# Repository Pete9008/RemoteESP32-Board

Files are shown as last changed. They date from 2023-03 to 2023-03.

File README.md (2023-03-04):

# RemoteESP32-Board
Stand alone 12V ESP32 module with SD card and RS485 and CAN bus interfaces

# Usage
This board is intended to be used with this firmware: https://github.com/Pete9008/esp32-web-interface/tree/Remote485 which currently supports use of the RS485 interface in either half or full duplex mode.

The BOM reflects the build for full duplex (4-wire RS485).  To use this the following line in the firmware needs to be commented out:
line88 - //#define RS485_HALF_DUPLEX 1

To use in half duplex mode (2-wire RS485) resistors R23 and R24 must have zero ohm links fitted (Note - This mode is not compatible with the standard OpenInverter firmware.

The firmware does not currently support CAN bus operation.  The CAN interface is currently untested.

# Powering
The board needs a 12V power supply connected on header J4.

0V connects to Pin-2
12V connects to Pin-1 (WiFi only mode)
12V connects to Pin-3 (SD card logging mode)

If power is supplied on Pin-1 then SD card logging is disabled (SD card files can still be read over the web interface though).

If power is supplied on Pin-3 then SD card logging will start (but only while there is no connection on the WiFi).

Note - Not all OpenInverter firmware versions support logging.

# SD Card Interface
The SD card uses the SDIO interface to allow high speed logging.  This requires a pull up on the D2 line (GPIO12) which prevents ESP32-WROOM-32E modules from booting from internal flash.

If the SD card is not used do not populate R9 (D2 pullup).

If the SD card is required then the module must have the flash voltage selection eFuses burned BEFORE resistor R9 is fitted.  See https://docs.espressif.com/projects/esp-idf/en/latest/esp32/api-reference/peripherals/sd_pullup_requirements.html for details of the fuse burning process.

# Programming Interface
Header J3 provides a programming interface for the board.  An external USB to 3V3 TTL 232 converter dongle is required to connect to this header.  To place the ESP32 into programming mode pins 1 and 2 of the header must be linked.  Pin-6 on the header can then either be grounded manually to reset the ESP32 and enter programming mode or can connected to RTS on the dongle (a reset will then be generated automatically by the esptool programming software).  The Tx line on the dongle connects to header Pin-4 and the Rx line to header Pin-5.  Header Pin-1 should connect to dongle 0V/GND.

Power during programming must be supplied by connecting 12V on the power header J4.

# Enclosure
Two versions of a 3D printable enclosure are included:
RemoteESP32_Enclosure_NoBat.FCStd - Slim enclosure but without enough space for the RTC backup battery.
RemoteESP32_Enclosure_Bat.FCStd - Larger enclosure with space for the RTC battery.

Both are in FreeCAD format.  .stl files for the enclosure base and lid are also included.

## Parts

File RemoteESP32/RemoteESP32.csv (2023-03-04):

Source: | /home/pete/Kicad/RemoteESP32/RemoteESP32/RemoteESP32.kicad_sch
Date: | Sat 04 Mar 2023 18:39:13 GMT
Tool: | Eeschema 6.0.0-d3dd2cf0fa~116~ubuntu18.04.1
Generator: | /usr/share/kicad/plugins/bom_csv_grouped_by_value.py
Component Count: | 58
Individual Components:
Item | Qty | Reference(s) | Value | LibPart | Footprint | Datasheet | Part | Voltage
 |  | BT1 | BR1225 | Device:Battery_Cell | Battery:Battery_Panasonic_CR1220-VCN_Vertical_CircularHoles | ~
 |  | C1 | 10u | Device:C | Capacitor_SMD:C_1206_3216Metric | ~ | CL31A106MBHNNNE | 50V
 |  | C2 | 100n | Device:C | Capacitor_SMD:C_0603_1608Metric | ~
 |  | C3 | 100n | Device:C | Capacitor_SMD:C_0603_1608Metric | ~
 |  | C4 | 100n | Device:C | Capacitor_SMD:C_0603_1608Metric | ~
 |  | C5 | 100n | Device:C | Capacitor_SMD:C_0603_1608Metric | ~
 |  | C6 | 100n | Device:C | Capacitor_SMD:C_0603_1608Metric | ~
 |  | C7 | 10u 50V | Device:C | Capacitor_SMD:C_1206_3216Metric | ~ | CL31A106MBHNNNE
 |  | C8 | 220p | Device:C | Capacitor_SMD:C_0603_1608Metric | ~
 |  | C9 | 100u | Device:C_Polarized | Capacitor_Tantalum_SMD:CP_EIA-7343-31_Kemet-D | ~ |  | 10V
 |  | C10 | 100n | Device:C | Capacitor_SMD:C_0603_1608Metric | ~
 |  | C11 | 10u | Device:C | Capacitor_SMD:C_1206_3216Metric | ~ | CL31A106MBHNNNE | 50V
 |  | C12 | 100n | Device:C | Capacitor_SMD:C_0603_1608Metric | ~
 |  | C13 | 100n | Device:C | Capacitor_SMD:C_0603_1608Metric | ~
 |  | D1 | MRA4003T3G | Diode:MRA4003T3G | Diode_SMD:D_SMA | http://www.onsemi.com/pub_link/Collateral/MRA4003T3-D.PDF
 |  | D2 | BAS40-04 | Diode:BAS40-04 | Package_TO_SOT_SMD:SOT-23 | http://www.vishay.com/docs/85701/bas40v.pdf | BAS40-04
 |  | D3 | BAS40-04 | Diode:BAS40-04 | Package_TO_SOT_SMD:SOT-23 | http://www.vishay.com/docs/85701/bas40v.pdf | BAS40-04
 |  | D4 | MRA4003T3G | Diode:MRA4003T3G | Diode_SMD:D_SMA | http://www.onsemi.com/pub_link/Collateral/MRA4003T3-D.PDF
 |  | D5 | PMEG60T30ELP | Diode:PMEG60T30ELR | Diode_SMD:D_SOD-128 | https://assets.nexperia.com/documents/data-sheet/PMEG60T30ELR.pdf | PMEG60T30ELP
 |  | H1 | MountingHole | Mechanical:MountingHole | MountingHole:MountingHole_2.2mm_M2_DIN965 | ~
 |  | H2 | MountingHole | Mechanical:MountingHole | MountingHole:MountingHole_2.2mm_M2_DIN965 | ~
 |  | H3 | MountingHole | Mechanical:MountingHole | MountingHole:MountingHole_2.2mm_M2_DIN965 | ~
 |  | H4 | MountingHole | Mechanical:MountingHole | MountingHole:MountingHole_2.2mm_M2_DIN965 | ~
 |  | J1 | Conn_01x07 | Connector_Generic:Conn_01x07 | Connector_Molex:Molex_KK-254_AE-6410-07A_1x07_P2.54mm_Vertical | ~
 |  | J2 | Molex_104031-0811 | Connector:Micro_SD_Card_Det_Hirose_DM3AT | Connector_Card:microSD_HC_Molex_104031-0811 | https://www.hirose.com/product/en/download_file/key_name/DM3/category/Catalog/doc_file_id/49662/?item_id=195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 | 104031-0811
 |  | J3 | Conn_01x06 | Connector_Generic:Conn_01x06 | Connector_PinHeader_2.54mm:PinHeader_1x06_P2.54mm_Vertical | ~
 |  | J4 | Conn_01x03 | Connector_Generic:Conn_01x03 | Connector_Molex:Molex_KK-254_AE-6410-03A_1x03_P2.54mm_Vertical | ~
 |  | L1 | 100u | Device:L | Inductor_SMD:L_Bourns_SRR1260 | ~ | SRR1260-101M
 |  | R1 | 10k | Device:R | Resistor_SMD:R_0603_1608Metric | ~
 |  | R2 | NF | Device:R | Resistor_SMD:R_0603_1608Metric | ~
 |  | R3 | 51k | Device:R | Resistor_SMD:R_0603_1608Metric | ~
 |  | R4 | 10k | Device:R | Resistor_SMD:R_0603_1608Metric | ~
 |  | R5 | NF | Device:R | Resistor_SMD:R_0603_1608Metric | ~
 |  | R6 | 10k | Device:R | Resistor_SMD:R_0603_1608Metric | ~
 |  | R7 | 10k | Device:R | Resistor_SMD:R_0603_1608Metric | ~
 |  | R8 | 10k | Device:R | Resistor_SMD:R_0603_1608Metric | ~
 |  | R9 | 10k | Device:R | Resistor_SMD:R_0603_1608Metric | ~
 |  | R10 | 10k | Device:R | Resistor_SMD:R_0603_1608Metric | ~
 |  | R11 | NF | Device:R | Resistor_SMD:R_0603_1608Metric | ~
 |  | R12 | 10k | Device:R | Resistor_SMD:R_0603_1608Metric | ~
 |  | R13 | 10k | Device:R | Resistor_SMD:R_0603_1608Metric | ~
 |  | R14 | 10k | Device:R | Resistor_SMD:R_0603_1608Metric | ~
 |  | R15 | 10k | Device:R | Resistor_SMD:R_0603_1608Metric | ~
 |  | R16 | 2k2 | Device:R | Resistor_SMD:R_0603_1608Metric | ~
 |  | R17 | 0R4 | Device:R | Resistor_SMD:R_1206_3216Metric | ~
 |  | R18 | 3k6 | Device:R | Resistor_SMD:R_0603_1608Metric | ~
 |  | R19 | 2k2 | Device:R | Resistor_SMD:R_0603_1608Metric | ~
 |  | R20 | 2k2 | Device:R | Resistor_SMD:R_0603_1608Metric | ~
 |  | R21 | 120R | Device:R | Resistor_SMD:R_0603_1608Metric | ~
 |  | R22 | 120R | Device:R | Resistor_SMD:R_0603_1608Metric | ~
 |  | R23 | NF | Device:R | Resistor_SMD:R_0603_1608Metric | ~
 |  | R24 | NF | Device:R | Resistor_SMD:R_0603_1608Metric | ~
 |  | U1 | SN65HVD230 | Interface_CAN_LIN:SN65HVD230 | Package_SO:SOIC-8_3.9x4.9mm_P1.27mm | http://www.ti.com/lit/ds/symlink/sn65hvd230.pdf
 |  | U2 | PCF8523T | Timer_RTC:PCF8523T | Package_SO:SOIC-8_3.9x4.9mm_P1.27mm | https://www.nxp.com/docs/en/data-sheet/PCF8523.pdf
 |  | U3 | ISL83076E | project:ISL83070 | Package_SO:SO-14_3.9x8.65mm_P1.27mm
 |  | U4 | MC33063AD | Regulator_Switching:MC33063AD | Package_SO:SOIC-8_3.9x4.9mm_P1.27mm | http://www.onsemi.com/pub_link/Collateral/MC34063A-D.PDF | MC33063AD
 |  | U5 | ESP32-WROOM-32E | RF_Module:ESP32-WROOM-32D | RF_Module:ESP32-WROOM-32 | https://www.espressif.com/sites/default/files/documentation/esp32-wroom-32d_esp32-wroom-32u_datasheet_en.pdf
 |  | Y1 | 32.768kHz | Device:Crystal_GND3_Small | Crystal:Crystal_AT310_D3.0mm_L10.0mm_Horizontal_1EP_style2 | ~
Collated Components:
Item | Qty | Reference(s) | Value | LibPart | Footprint | Datasheet | Part | Voltage
1 | 1 | BT1 | BR1225 | Device:Battery_Cell | Battery:Battery_Panasonic_CR1220-VCN_Vertical_CircularHoles | ~
2 | 2 | C1, C11 | 10u | Device:C | Capacitor_SMD:C_1206_3216Metric | ~ | CL31A106MBHNNNE | 50V
3 | 8 | C2, C3, C4, C5, C6, C10, C12, C13 | 100n | Device:C | Capacitor_SMD:C_0603_1608Metric | ~
4 | 1 | C7 | 10u 50V | Device:C | Capacitor_SMD:C_1206_3216Metric | ~ | CL31A106MBHNNNE
5 | 1 | C8 | 220p | Device:C | Capacitor_SMD:C_0603_1608Metric | ~
6 | 1 | C9 | 100u | Device:C_Polarized | Capacitor_Tantalum_SMD:CP_EIA-7343-31_Kemet-D | ~ |  | 10V
7 | 2 | D1, D4 | MRA4003T3G | Diode:MRA4003T3G | Diode_SMD:D_SMA | http://www.onsemi.com/pub_link/Collateral/MRA4003T3-D.PDF
8 | 2 | D2, D3 | BAS40-04 | Diode:BAS40-04 | Package_TO_SOT_SMD:SOT-23 | http://www.vishay.com/docs/85701/bas40v.pdf | BAS40-04
9 | 1 | D5 | PMEG60T30ELP | Diode:PMEG60T30ELR | Diode_SMD:D_SOD-128 | https://assets.nexperia.com/documents/data-sheet/PMEG60T30ELR.pdf | PMEG60T30ELP
10 | 4 | H1, H2, H3, H4 | MountingHole | Mechanical:MountingHole | MountingHole:MountingHole_2.2mm_M2_DIN965 | ~
11 | 1 | J1 | Conn_01x07 | Connector_Generic:Conn_01x07 | Connector_Molex:Molex_KK-254_AE-6410-07A_1x07_P2.54mm_Vertical | ~
12 | 1 | J2 | Molex_104031-0811 | Connector:Micro_SD_Card_Det_Hirose_DM3AT | Connector_Card:microSD_HC_Molex_104031-0811 | https://www.hirose.com/product/en/download_file/key_name/DM3/category/Catalog/doc_file_id/49662/?item_id=195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 | 104031-0811
13 | 1 | J3 | Conn_01x06 | Connector_Generic:Conn_01x06 | Connector_PinHeader_2.54mm:PinHeader_1x06_P2.54mm_Vertical | ~
14 | 1 | J4 | Conn_01x03 | Connector_Generic:Conn_01x03 | Connector_Molex:Molex_KK-254_AE-6410-03A_1x03_P2.54mm_Vertical | ~
15 | 1 | L1 | 100u | Device:L | Inductor_SMD:L_Bourns_SRR1260 | ~ | SRR1260-101M
16 | 11 | R1, R4, R6, R7, R8, R9, R10, R12, R13, R14, R15 | 10k | Device:R | Resistor_SMD:R_0603_1608Metric | ~
17 | 5 | R2, R5, R11, R23, R24 | NF | Device:R | Resistor_SMD:R_0603_1608Metric | ~
18 | 1 | R3 | 51k | Device:R | Resistor_SMD:R_0603_1608Metric | ~
19 | 3 | R16, R19, R20 | 2k2 | Device:R | Resistor_SMD:R_0603_1608Metric | ~
20 | 1 | R17 | 0R4 | Device:R | Resistor_SMD:R_1206_3216Metric | ~
21 | 1 | R18 | 3k6 | Device:R | Resistor_SMD:R_0603_1608Metric | ~
22 | 2 | R21, R22 | 120R | Device:R | Resistor_SMD:R_0603_1608Metric | ~
23 | 1 | U1 | SN65HVD230 | Interface_CAN_LIN:SN65HVD230 | Package_SO:SOIC-8_3.9x4.9mm_P1.27mm | http://www.ti.com/lit/ds/symlink/sn65hvd230.pdf
24 | 1 | U2 | PCF8523T | Timer_RTC:PCF8523T | Package_SO:SOIC-8_3.9x4.9mm_P1.27mm | https://www.nxp.com/docs/en/data-sheet/PCF8523.pdf
25 | 1 | U3 | ISL83076E | project:ISL83070 | Package_SO:SO-14_3.9x8.65mm_P1.27mm
26 | 1 | U4 | MC33063AD | Regulator_Switching:MC33063AD | Package_SO:SOIC-8_3.9x4.9mm_P1.27mm | http://www.onsemi.com/pub_link/Collateral/MC34063A-D.PDF | MC33063AD
27 | 1 | U5 | ESP32-WROOM-32E | RF_Module:ESP32-WROOM-32D | RF_Module:ESP32-WROOM-32 | https://www.espressif.com/sites/default/files/documentation/esp32-wroom-32d_esp32-wroom-32u_datasheet_en.pdf
28 | 1 | Y1 | 32.768kHz | Device:Crystal_GND3_Small | Crystal:Crystal_AT310_D3.0mm_L10.0mm_Horizontal_1EP_style2 | ~

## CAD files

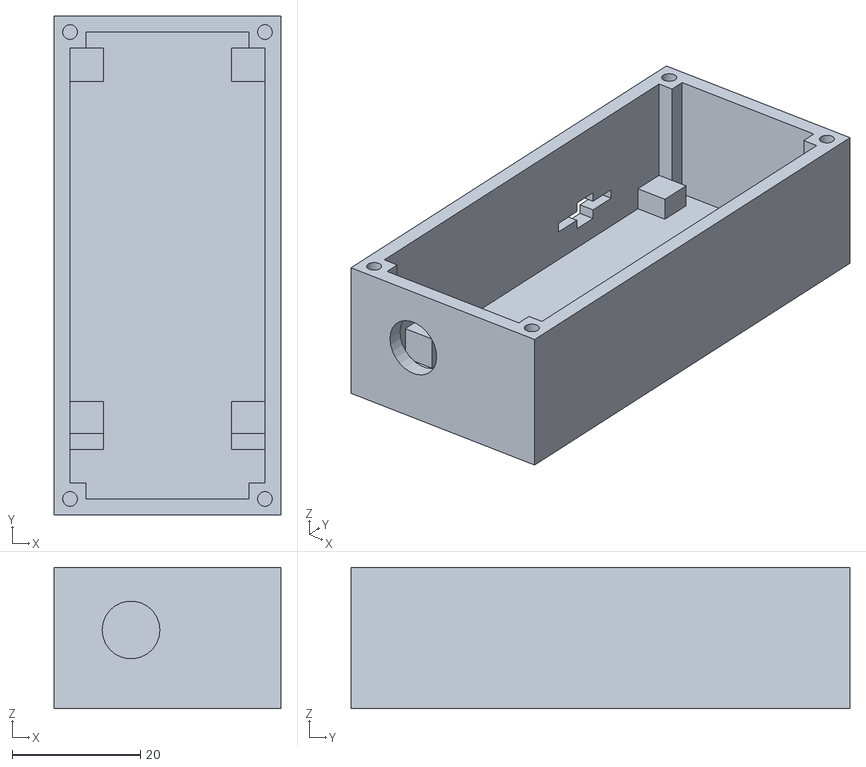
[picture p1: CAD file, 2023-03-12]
Enclosure/RemoteESP32_Enclosure_Bat-Base.stl
35.4 x 77.7 x 22.0

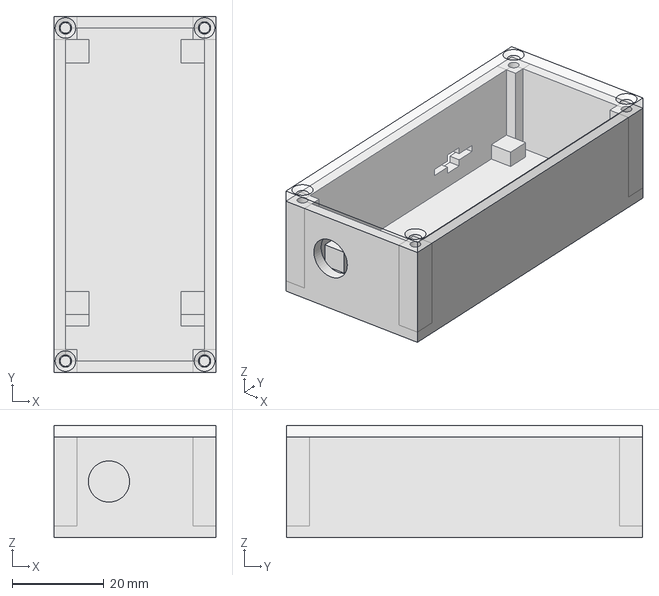
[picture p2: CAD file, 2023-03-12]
Enclosure/RemoteESP32_Enclosure_Bat.FCStd
35.4 x 77.7 x 24.5 mm
Base
Lid

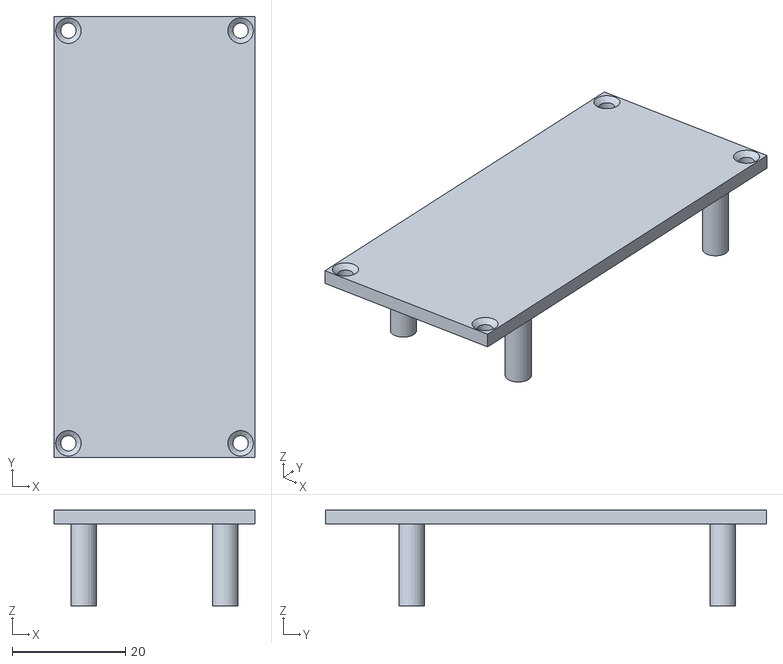
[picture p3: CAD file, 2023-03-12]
Enclosure/RemoteESP32_Enclosure_Bat-Lid.stl
35.4 x 77.7 x 16.9

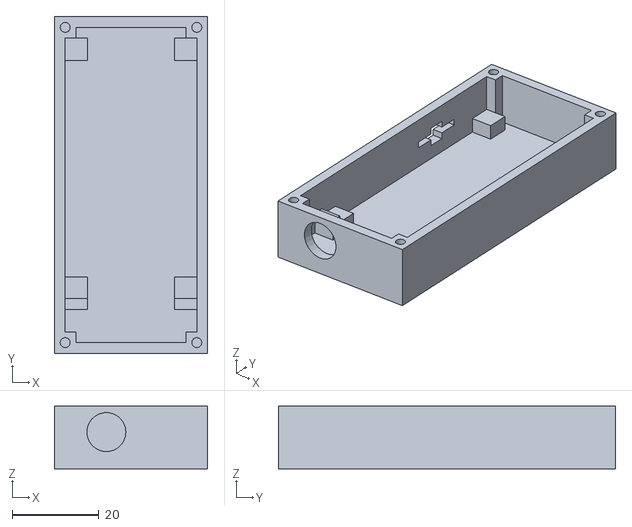
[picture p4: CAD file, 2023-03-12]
Enclosure/RemoteESP32_Enclosure_NoBat-Base.stl
35.4 x 77.7 x 14.5

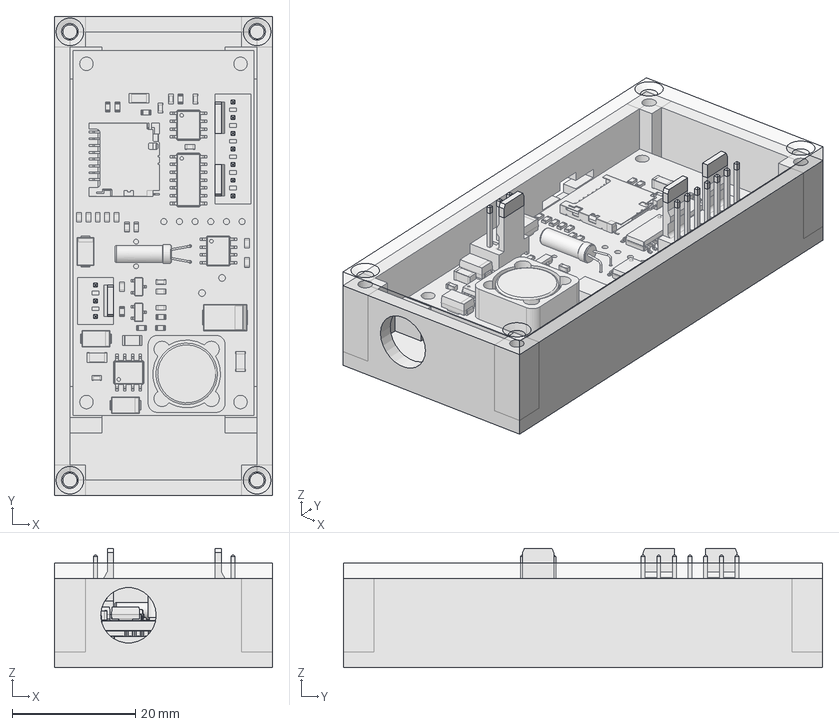
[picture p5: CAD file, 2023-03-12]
Enclosure/RemoteESP32_Enclosure_NoBat.FCStd
35.4 x 77.7 x 19.4 mm
RemoteESP32
Base
Lid

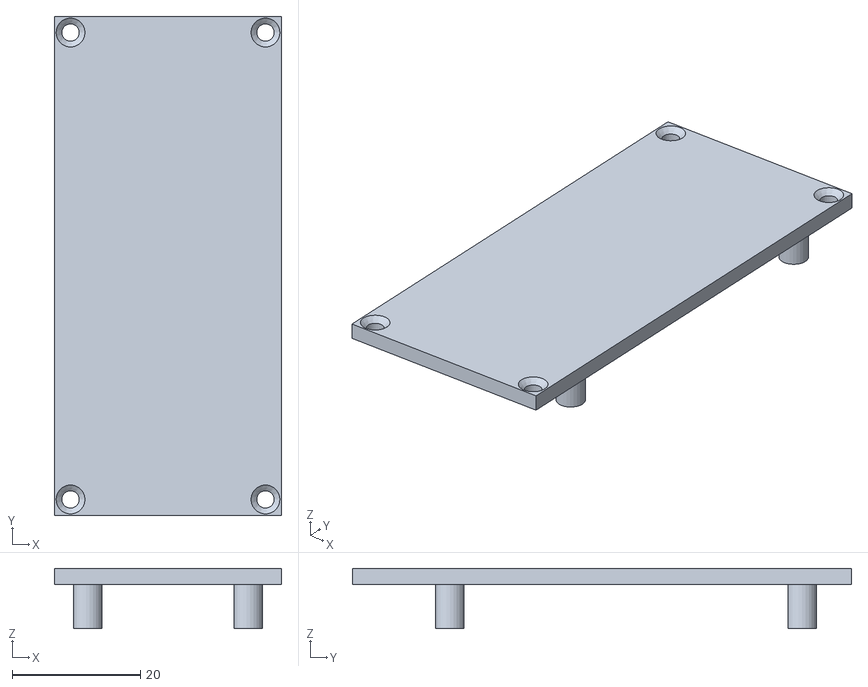
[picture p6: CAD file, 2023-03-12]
Enclosure/RemoteESP32_Enclosure_NoBat-Lid.stl
35.4 x 77.7 x 9.40

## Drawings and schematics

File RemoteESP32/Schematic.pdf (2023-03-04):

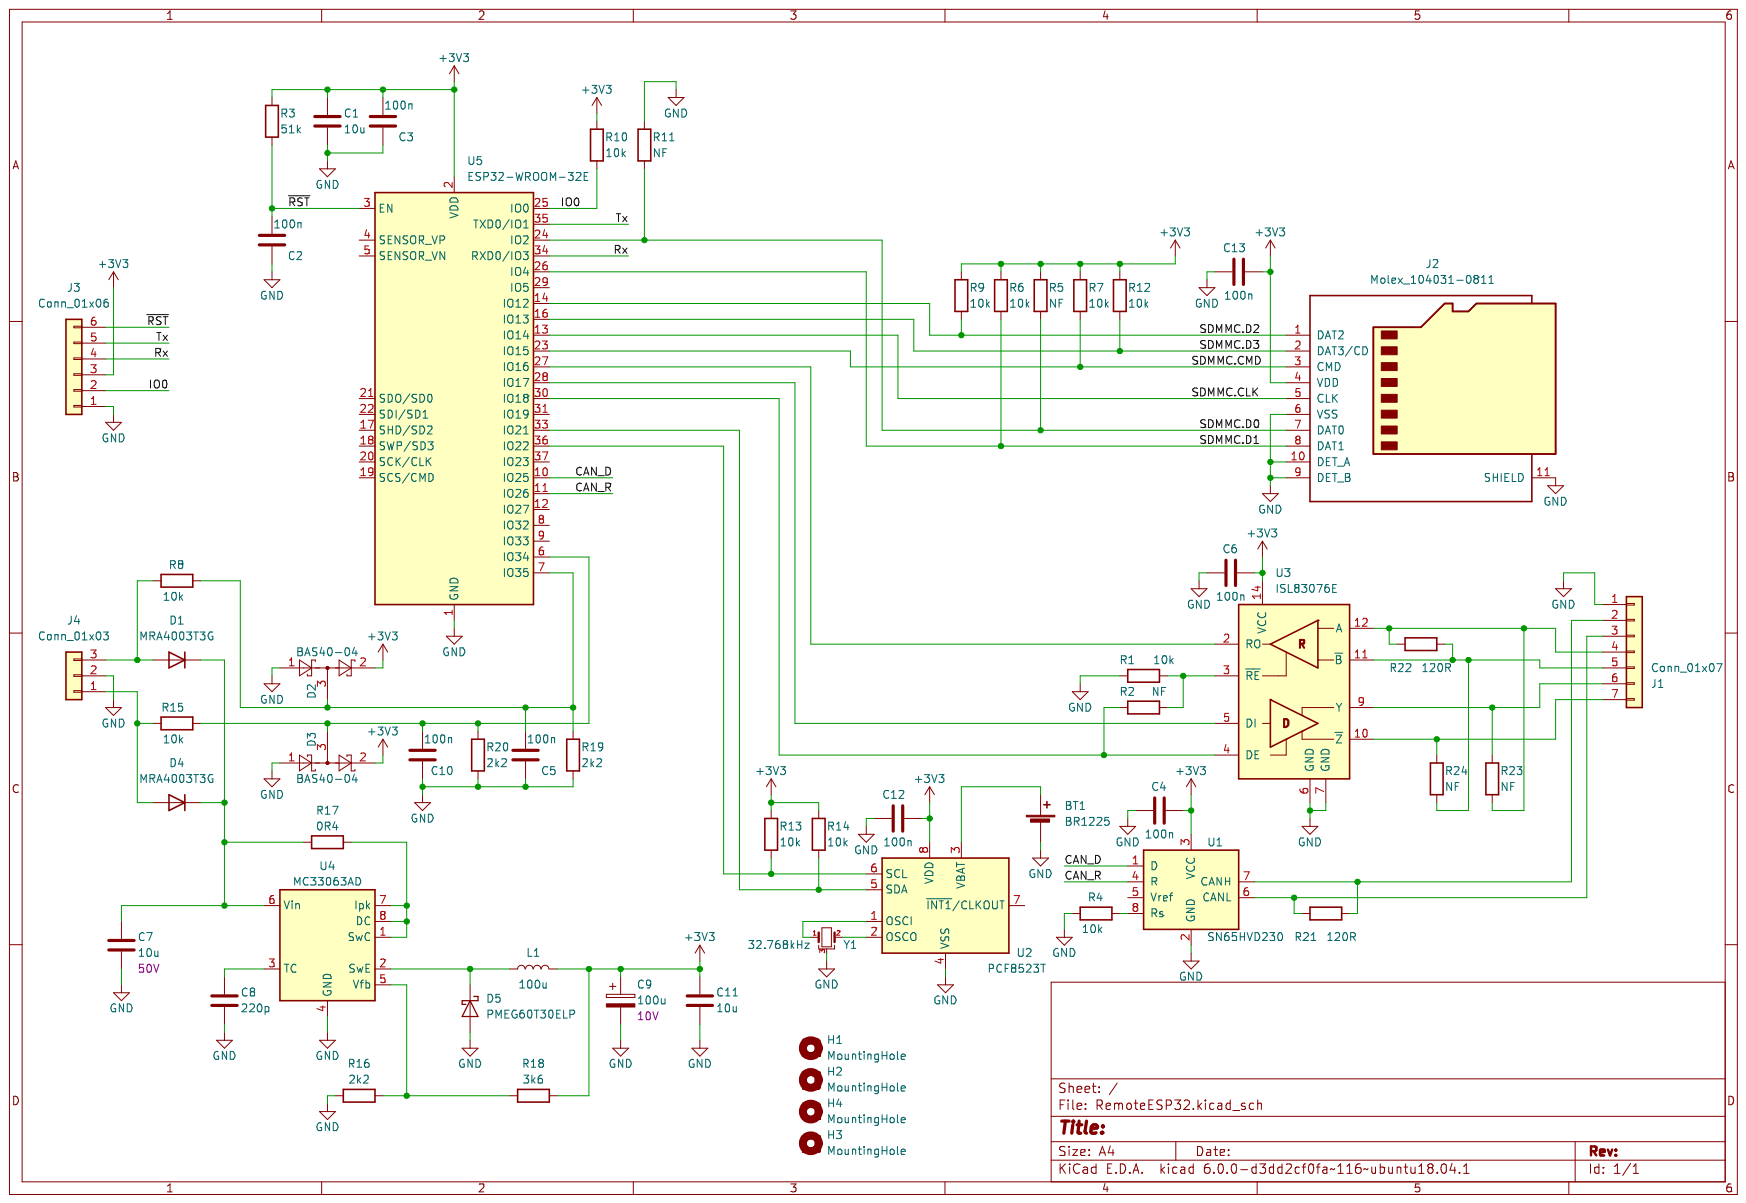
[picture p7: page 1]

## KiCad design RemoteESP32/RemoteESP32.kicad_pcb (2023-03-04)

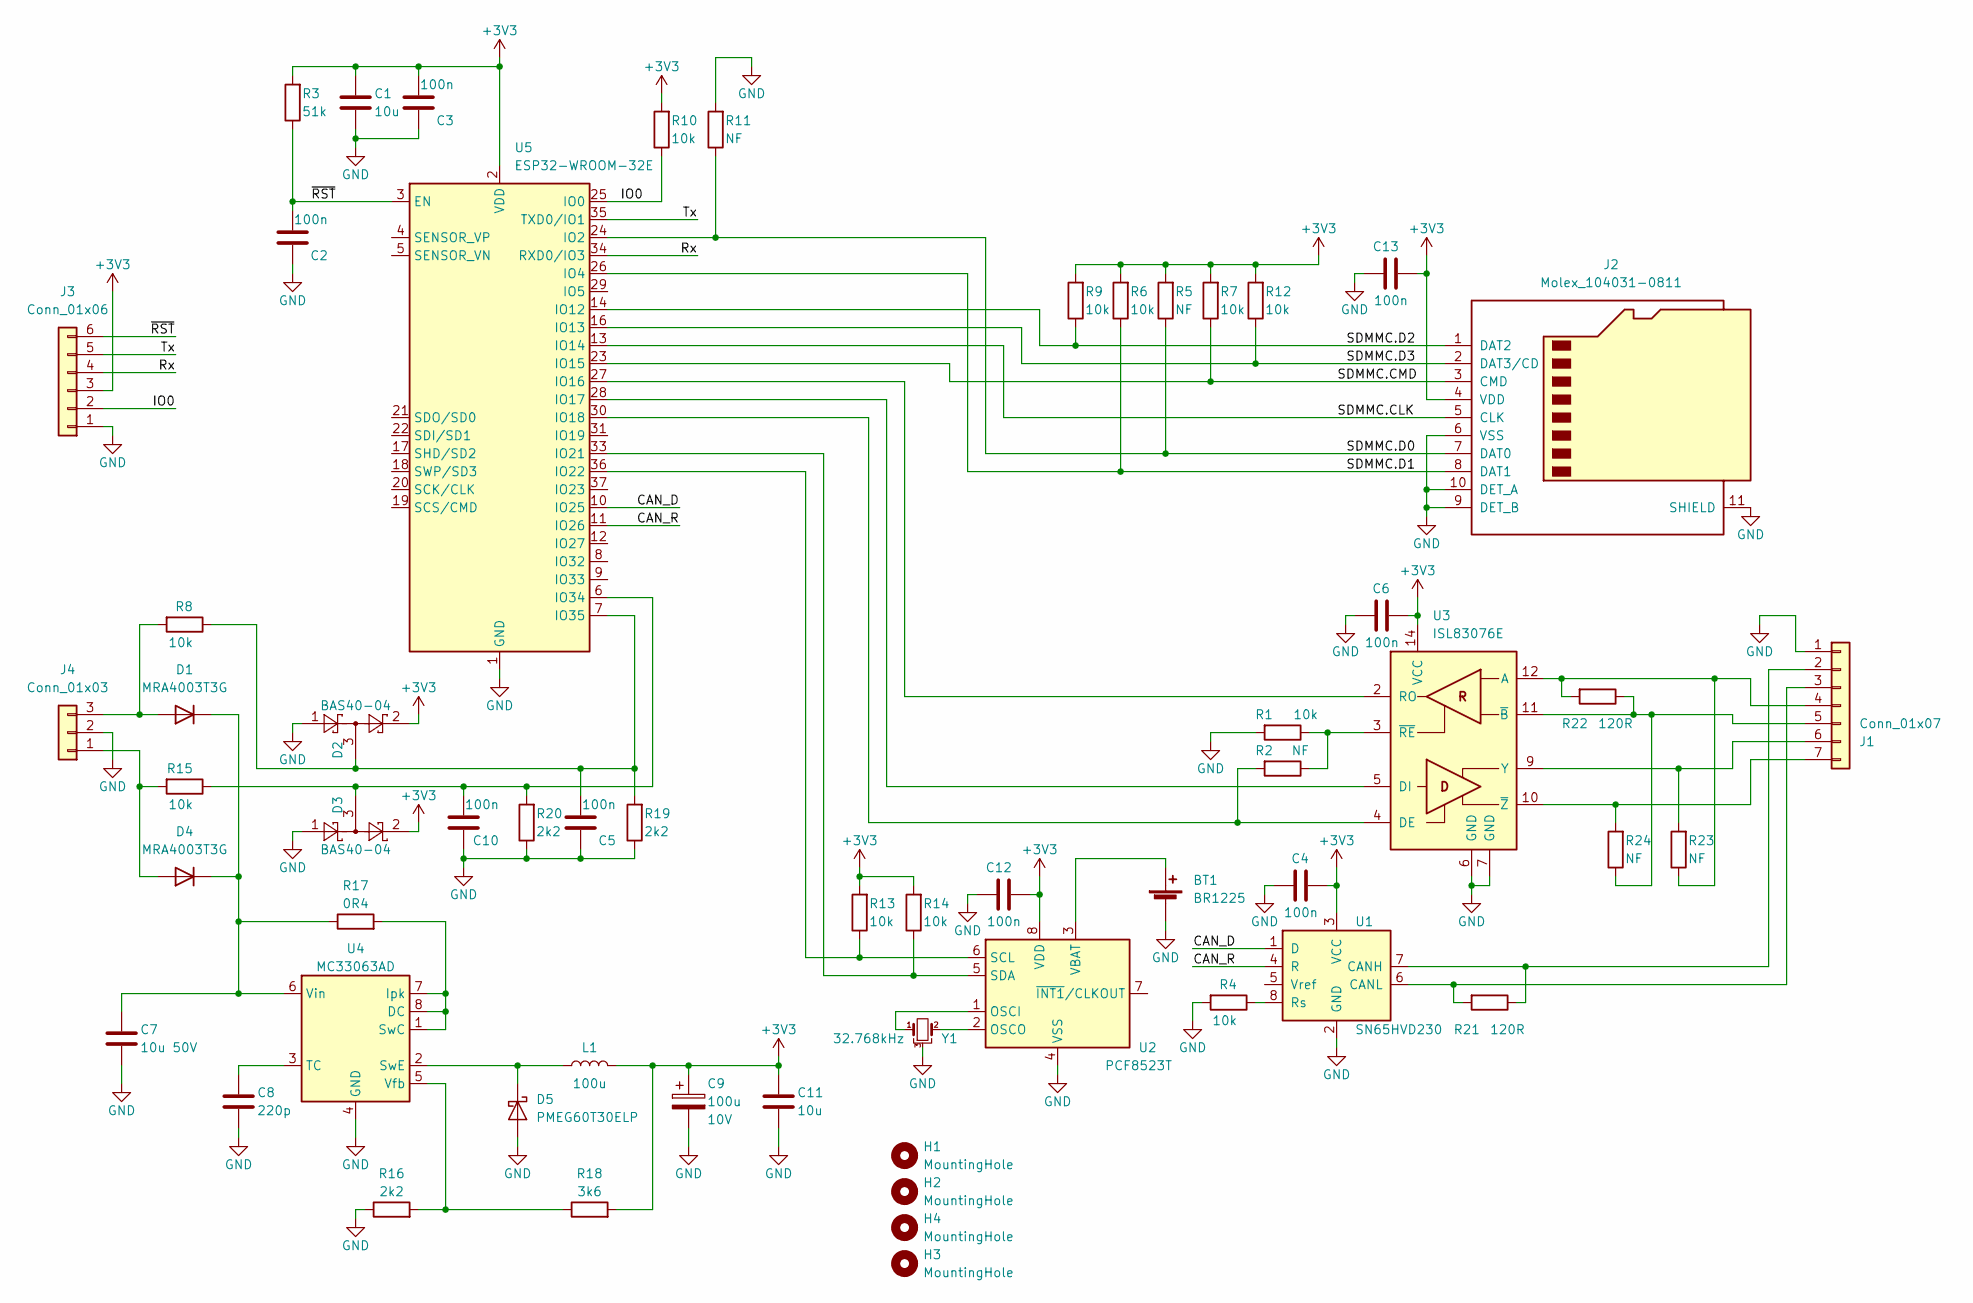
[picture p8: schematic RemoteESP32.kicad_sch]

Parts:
BT1: BR1225; Battery_Panasonic_CR1220-VCN_Vertical_CircularHoles
C1, C11: 10u; C_1206_3216Metric; Voltage 50V; Part CL31A106MBHNNNE
C2, C3, C4, C5, C6, C10, C12, C13: 100n; C_0603_1608Metric
C7: 10u 50V; C_1206_3216Metric; Part CL31A106MBHNNNE
C8: 220p; C_0603_1608Metric
C9: 100u; CP_EIA-7343-31_Kemet-D; Voltage 10V
D1, D4: MRA4003T3G; D_SMA
D2, D3: BAS40-04; SOT-23; Part BAS40-04
D5: PMEG60T30ELP; D_SOD-128; Part PMEG60T30ELP
H1, H2, H3, H4: MountingHole; MountingHole_2.2mm_M2_DIN965
J1: Conn_01x07; Molex_KK-254_AE-6410-07A_1x07_P2.54mm_Vertical
J2: Molex_104031-0811; microSD_HC_Molex_104031-0811; Part 104031-0811
J3: Conn_01x06; PinHeader_1x06_P2.54mm_Vertical
J4: Conn_01x03; Molex_KK-254_AE-6410-03A_1x03_P2.54mm_Vertical
L1: 100u; L_Bourns_SRR1260; Part SRR1260-101M
R1, R4, R6, R7, R8, R9, R10, R12, R13, R14, R15: 10k; R_0603_1608Metric
R2, R5, R11, R23, R24: NF; R_0603_1608Metric
R3: 51k; R_0603_1608Metric
R16, R19, R20: 2k2; R_0603_1608Metric
R17: 0R4; R_1206_3216Metric
R18: 3k6; R_0603_1608Metric
R21, R22: 120R; R_0603_1608Metric
U1: SN65HVD230; SOIC-8_3.9x4.9mm_P1.27mm
U2: PCF8523T; SOIC-8_3.9x4.9mm_P1.27mm
U3: ISL83076E; SO-14_3.9x8.65mm_P1.27mm
U4: MC33063AD; SOIC-8_3.9x4.9mm_P1.27mm; Part MC33063AD
U5: ESP32-WROOM-32E; ESP32-WROOM-32
Y1: 32.768kHz; Crystal_AT310_D3.0mm_L10.0mm_Horizontal_1EP_style2

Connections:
+3V3: C1.1, C3.2, C4.2, C6.2, C9.1, C11.1, C12.2, C13.2, D2.2, D3.2, J2.4 (VDD), J3.3, L1.2, R3.2, R5.2, R6.2, R7.2, R9.2, R10.2, R12.2, R13.2, R14.2, R18.2, U1.3 (VCC), U2.8 (VDD), U3.14 (VCC), U5.2 (VDD)
/CAN_D: U1.1 (D), U5.10 (IO25)
/CAN_R: U1.4 (R), U5.11 (IO26)
/IO0: J3.2, R10.1, U5.25 (IO0)
/Rx: J3.4, U5.34 (RXD0/IO3)
/SDMMC.CLK: J2.5 (CLK), U5.13 (IO14)
/SDMMC.CMD: J2.3 (CMD), R7.1, U5.23 (IO15)
/SDMMC.D0: J2.7 (DAT0), R5.1, R11.1, U5.24 (IO2)
/SDMMC.D1: J2.8 (DAT1), R6.1, U5.26 (IO4)
/SDMMC.D2: J2.1 (DAT2), R9.1, U5.14 (IO12)
/SDMMC.D3: J2.2 (DAT3/CD), R12.1, U5.16 (IO13)
/Tx: J3.5, U5.35 (TXD0/IO1)
/~RST: C2.2, J3.6, R3.1, U5.3 (EN)
GND: BT1.2 (-), C1.2, C2.1, C3.1, C4.1, C5.1, C6.1, C7.2, C8.2, C9.2, C10.1, C11.2, C12.1, C13.1, D2.1, D3.1, D5.2 (A), J1.1, J2.6 (VSS), J2.9 (DET_B), J2.10 (DET_A), J2.11 (SHIELD), J3.1, J4.2, R1.2, R4.2, R11.2, R16.1, R19.1, R20.1, U1.2 (GND), U2.4 (VSS), U3.6 (GND), U3.7 (GND), U4.4 (GND), U5.1 (GND), U5.15 (GND), U5.38 (GND), U5.39 (GND), Y1.3
unnamed: BT1.1 (+), U2.3 (VBAT)
unnamed: C5.2, D2.3, R8.1, R19.2, U5.7 (IO35)
unnamed: C7.1, D1.1 (K), D4.1 (K), R17.1, U4.6 (Vin)
unnamed: C8.1, U4.3 (TC)
unnamed: C10.2, D3.3, R15.1, R20.2, U5.6 (IO34)
unnamed: D1.2 (A), J4.3, R8.2
unnamed: D4.2 (A), J4.1, R15.2
unnamed: D5.1 (K), L1.1, U4.2 (SwE)
unnamed: J1.2, R21.1, U1.7 (CANH)
unnamed: J1.3, R21.2, U1.6 (CANL)
unnamed: J1.4, R22.2, R23.1, U3.12 (A)
unnamed: J1.5, R22.1, R24.1, U3.11 (~B)
unnamed: J1.6, R23.2, U3.9 (Y)
unnamed: J1.7, R24.2, U3.10 (~Z)
unnamed: R1.1, R2.1, U3.3 (~RE)
unnamed: R2.2, U3.4 (DE), U5.30 (IO18)
unnamed: R4.1, U1.8 (Rs)
unnamed: R13.1, U2.6 (SCL), U5.36 (IO22)
unnamed: R14.1, U2.5 (SDA), U5.33 (IO21)
unnamed: R16.2, R18.1, U4.5 (Vfb)
unnamed: R17.2, U4.1 (SwC), U4.7 (Ipk), U4.8 (DC)
unnamed: U2.1 (OSCI), Y1.1
unnamed: U2.2 (OSCO), Y1.2
unnamed: U3.2 (RO), U5.27 (IO16)
unnamed: U3.5 (DI), U5.28 (IO17)

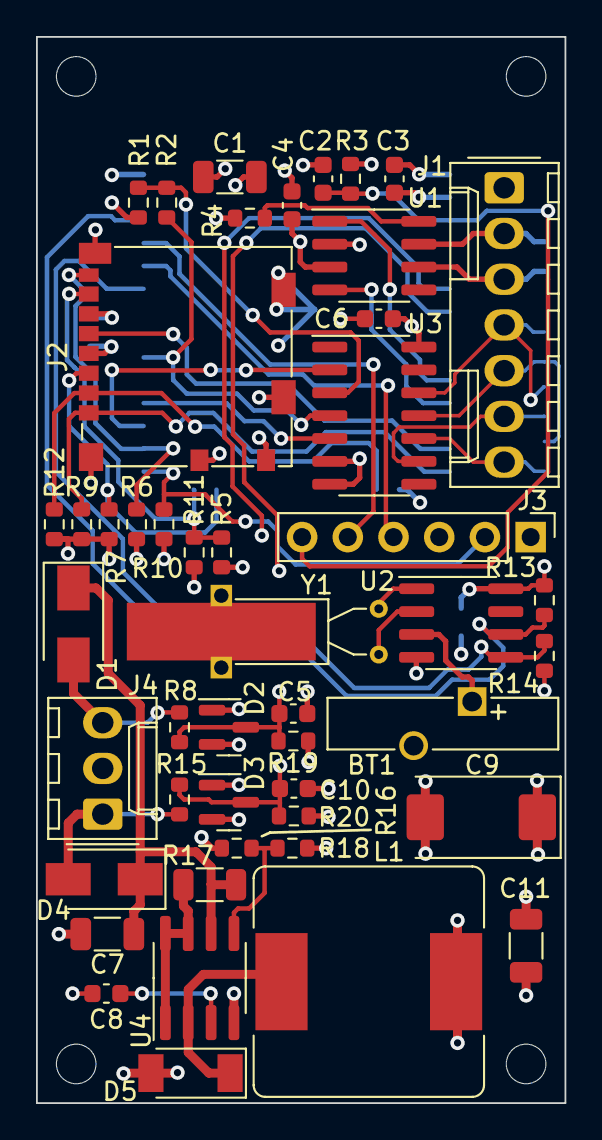
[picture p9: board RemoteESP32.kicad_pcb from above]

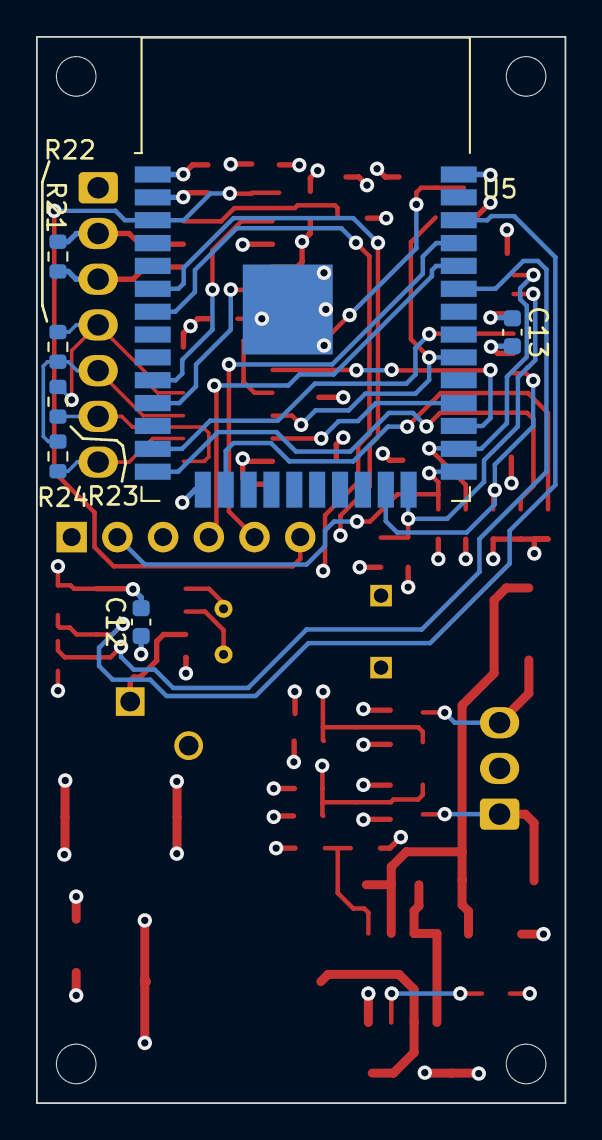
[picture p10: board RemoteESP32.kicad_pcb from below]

Board: 4 copper layers, 29.4 x 59.2 mm, 58 parts (7 on the bottom side), 39 nets.

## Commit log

2023-03-04 Added .csv BOM file
    [RemoteESP32.csv]
2023-03-12 Added enclosure model
    [RemoteESP32_Enclosure_Bat-Base.stl, RemoteESP32_Enclosure_Bat-Lid.stl, RemoteESP32_Enclosure_Bat.FCStd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]
